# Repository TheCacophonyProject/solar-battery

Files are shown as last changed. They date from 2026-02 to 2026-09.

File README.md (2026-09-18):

# Solar battery

KiCad projects for the solar battery hardware. The board itself is in
[`solar-BQ25798`](solar-BQ25798), with the shared symbols and footprints pulled
in as the [`kicad-library`](kicad-library) submodule.

[`panel-solar-battery.py`](panel-solar-battery.py) panelises the board with
[KiKit](https://github.com/yaqwsx/KiKit) into `.generated-pcbs/`, and adds the
DRC exclusions for the footprints that the panelisation cuts through, so the
generated panel passes DRC.

### Install dependencies
KiCad supplies the `pcbnew` python module as a system package, and it can't be
installed with pip, so the virtual environment has to be able to see it:
- `sudo apt-get install kicad`
- `python3 -m venv --system-site-packages venv`
- `source venv/bin/activate`
- `pip install kikit`

Check both halves are importable before running anything:
- `python -c "import pcbnew, kikit"`

### Generating the panel
With the virtual environment activated, from the root of the repo:
- `python panel-solar-battery.py`

The script needs `kikit` on the `PATH` (it shells out to `kikit panelize`) as
well as `pcbnew` importable, which is why it is run from inside the virtual
environment rather than with the system python.

### Notes
- `.generated-pcbs/` is ignored by git — it is rebuilt from scratch on every
  run, and KiKit gives the footprints new UUIDs each time, so the DRC
  exclusions are only valid for the panel they were generated with.
- Getting the submodule if the checkout is fresh: `git submodule update --init`

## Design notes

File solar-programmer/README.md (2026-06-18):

# Solar Programmer

This is a hat to go on a Raspberry Pi Zero to help programming the solar batteries.

For the software to run look at [battery-programmer](https://github.com/TheCacophonyProject/battery-programmer)

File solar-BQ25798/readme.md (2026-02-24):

# Solar BQ25798

This is a 3S5P 18650 MPPT solar charger that uses a BQ25798 for the MPPT charger, BQ76920 for the balancer, and an ATtiny1616 for the charge controller.

The [firmware](https://github.com/TheCacophonyProject/solar-battery-firmware) and the PCB is a WIP.

## TODO

- Reduce trace resistances for power paths.
- Check resistance of the protection for the 18650, if too high look for alternatives.
- Tidy up of traces (bit of a mess at the moment)
- Add something so the ATtiny can check what version of the board it is (will maybe not be able to have the latest firmware work on all versions of the PCB)
- Bed of nails test fixture.
- Calculate shunt resistor value for the BQ76920 so it high enough for triggering over current discharges and short circuits.
- New 3D print for new layout of the components.

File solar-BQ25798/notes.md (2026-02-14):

## Notes from BQ25798 datasheet
### 1 Features
- Buck boost
- 1-4 cell batteries
- Input and charging current sensing
- Samples open circuit voltage MPPT
- Up to 24V, 30V absolute
- uA for battery only operation
- 500nA in charger shutdown mode
- Thermal regulation and thermal shutdown
- Input/battery OVP and OCP
- Charging safety timer
- Says only li-ion/li-polyer but the target charge voltage can be changed to suite a LiFePO4 4S setup 

### 7 Pin configuration and functions
- STAT: LED attached to help debugging while in development but is no needed in end product
- VBUS: recommended capacitor setup caused noise at low power charging. Check if adding more capacitance is not recommended.
- ~{QON}: Check if we need to use this for ship mode.
- ILIM_HIZ: Just pull up as the maximum current will be programmed through I2C
- SDRV: ship mosfet drive pin

### 8 Specifications
- Absolute max voltage of 30V
- Recommended max voltage of 24V
- 8.5 describes quiescent currents. Should use this to see what mode we should try to be in during night to reduce unneeded power losses.

### 9 Detailed Description
9.3.2 PROG Pin: Using 750MHz as that can work better at lower charge currents, and 3s cell count, even when using 4s LiFePO4 as the charge voltage range is 10-13.99V for 3s
- On boot should read the CELL bits to check that it is in the 3s and 750MHz

9.3.3 Device power up from battery without input source: This should only happen once when putting together the battery

9.3.4 Device Power Up from input Source: Need to check that in the process of putting the battery pack together it will boot up in combination with the cell balancer chip

9.3.4.1: Power Up REGN LDO: Don't use it for external circuits and not for ~{INT}

9.3.4.2 Poor Source qualification:
- Needs to stay in the voltage range while pulling up to 10mA
- PG_STAT is set high with a good source, ~{INT} is pulsed to notify host.
- If the voltage drops below the minimum voltage when pulling 10mA it will go into high impedance mode (EN_HIZ) for 7 minutes, we can trigger it to try again from the I2C master. We will want to do this as if a solar panel goes into shade for a bit we want it to try again.

9.3.4.3 ILIM_HIZ Pin:
- Will limit through software so this just gets pulled up to VREGN

9.3.4.4 Default VINDPM Setting:
- TODO

9.3.4.5 Input Source Type Detection:
- Runs Input Source Type Detection if AUTO_INDET_EN bit is set (default enabled)
- Do we want to just disable this?

9.3.4.5.1 D+/D– Detection Sets Input Current Limit:
- 

9.3.9.5:
- Set reg in  REG18_NTC_Control_1 for what voltage percentage it will be

9.3.10 ADC:
- Disable for low power when not needed.
- IBUS (positive in forward converter mode)
• IBAT (positive for charging)
• VBUS
• VPMID
• VBAT
• VSYS
• TS
• TDIE

9.3.11.1 STAT Pin:
- Can attached LED but remove LED for final product.

9.3.11.2 Interrupt to Host ( INT):
- Check status change when this triggers
- Disable some of the triggers for INT that we don't want.
- Just sends out a pulse, not held low

9.3.12 Ship FET Control:
TODO

9.3.12.1 Shutdown Mode:
- Will disable the I2C so probably not something we want to use.

9.3.12.2 Ship Mode
- Might be useful when trying to reduce power losses.

9.3.13 Protections:
- Monitor if any of the voltage and current monitoring triggers go off
- Monitor thermal regulation and set max temps

9.3.14 Serial interface:
- Just standard I2C device reading and writing to registers without crc

9.4.1:
- Handle the I2C WDT
- If I2C WDT triggers, make sure that we set all the registers again to what we want.

9.4.2 Register Bit Reset:
- register and the timer could be reset
to the default value by writing the REG_RST bit to 1
- Will want to use this on first power up from ATtiny so we know what state the chip is in

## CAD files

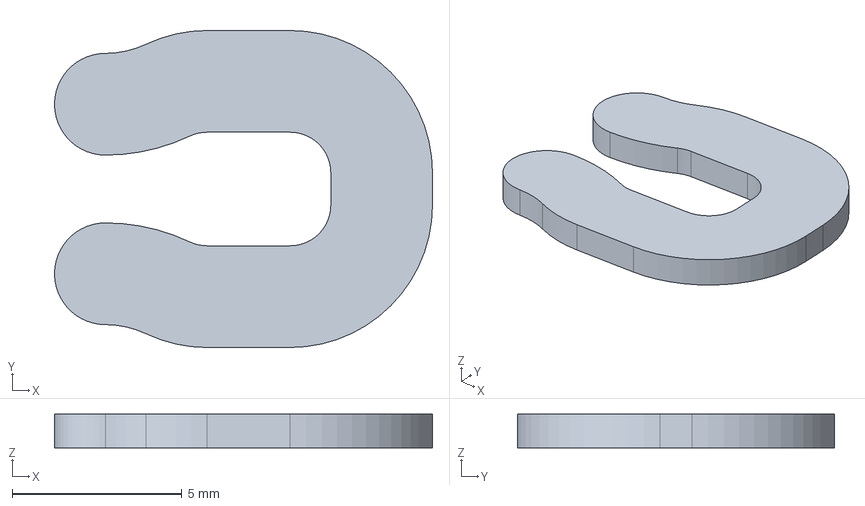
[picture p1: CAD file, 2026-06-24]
drawings/temp-sensor-thermal-relief.FCStd
11.2 x 9.35 x 1.00 mm

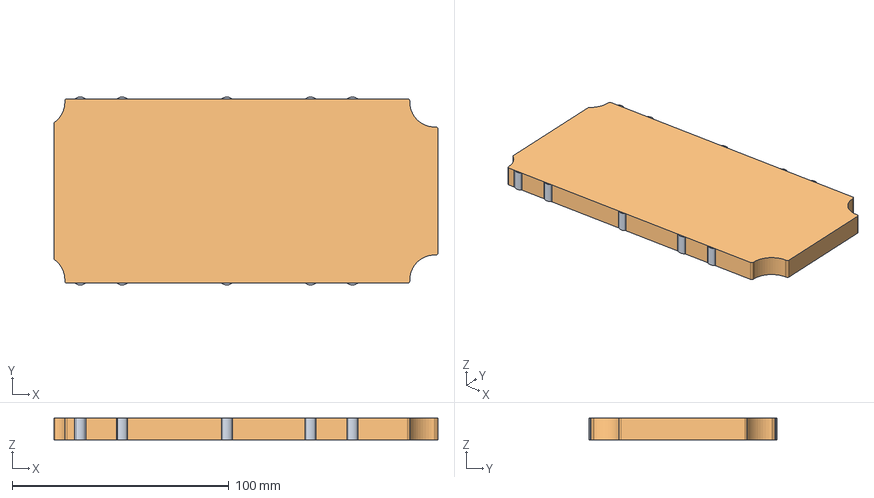
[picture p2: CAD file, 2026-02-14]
solar-BQ25798/drawings/solar-battery-boarder.FCStd
177.0 x 86.7 x 10.0 mm

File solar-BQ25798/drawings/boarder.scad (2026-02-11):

$fs=0.4;
$fa=4;


// ========== Boarder =============
// To make the boarder, we generate the boarder with the recommended maximum 
// measurements and then do an intersection from that with a rectangle.
// This makes it easy to resize/offset the boarder to fit in the case without 
// Needing to worry with being too big

// These are the maximum sizes that we want the boarder to be
width_max = 189;    // This is the width available for the back panel
depth_max = 89;     // This is the depth available for the back panel
corner_cutout = 15;             // For the corner cutouts this is the length that it is straight before it has its radius
corner_cutout_radius = 11.5;    // For the corner cutouts, this is the radius (not including the straight part)

// This is the size of the rectangle that will do an intersection with the maximum 
// boarder to get the final boarder.
// An offset is also used to make one end have more space for plugs.
depth = 85;
width = 177;
boarder_offset = 4;

// Distance from one battery cell to another.
bat_to_bat = 19.3;

h = 2;

module boarder2(height) {
    linear_extrude(height = height)
    import("/home/cam/Downloads/boarder3-Shape2DViewaaaaa.dxf"); 
}

module rec_from_points(x1, y1, x2, y2, r=0) {
    if (r == 0) {
        polygon(points=[[x1, y1], [x1, y2], [x2, y2], [x2, y1]]);
    } else {
        minkowski() {
            polygon(points=[[x1+r, y1+r], [x1+r, y2-r], [x2-r, y2-r], [x2-r, y1+r]]);
            circle(r = r);
        }
    }
}

tab_h=18;
tab_y=1.2;
tab_x=15.3;
tab_feet_y=4;
tab_feet_x=4.4;
tab_p = 35;

module tab_main() {
    // Body
    hull() {
        // Wider at the bottom to make putting it on the PCB easier.
        translate([0, 0, -1])
        linear_extrude(height = 1) 
        rec_from_points(x1 = -tab_x/2, y1 = -tab_y, x2 = tab_x/2, y2 = tab_y, r=0.4);
        linear_extrude(height = tab_h) 
        rec_from_points(x1 = -tab_x/2, y1 = -tab_y/2, x2 = tab_x/2, y2 = tab_y/2, r=0.4);
    }
    hull() {
        // Wider at the bottom to make putting it on the PCB easier.
        translate([0, -tab_y, h8])
        linear_extrude(height = 1) 
        rec_from_points(x1 = -tab_x/2, y1 = -tab_y/2-2, x2 = tab_x/2, y2 = tab_y, r=0.4);
        
        translate([0, 0, tab_h-1])
        linear_extrude(height = 1) 
        rec_from_points(x1 = -tab_x/2, y1 = -tab_y/2-1, x2 = tab_x/2, y2 = tab_y/2, r=0.4);
    }

    difference() {
        hull() {
            extra_width=5;
            translate([-(0)/2, tab_feet_y/2, -1])
            linear_extrude(height=2)
            rec_from_points(x1 = -bat_to_bat/2-extra_width/2, y1 = -tab_feet_y/2-1, x2 = bat_to_bat/2+extra_width/2, y2 = tab_feet_y/2);

            translate([-(0)/2, tab_feet_y/2-1.4, 5])
            cube([bat_to_bat+extra_width, 0.01, 1], center=true);
        }

        translate([0, -tab_p+39.85, -2])
        cylinder(d=3.3+1.8, h=5); 

        translate([bat_to_bat/2, -tab_p+39.85, -2])
        cylinder(d=3.3+1.8, h=5);
        translate([-bat_to_bat/2, -tab_p+39.85, -2])
        cylinder(d=3.3+1.8, h=5);    
    }   
}
// !tab_main();

module tab_positive() {
    tab_main();
    hull() {
        translate([0, 0, tab_h/2])
        cube([tab_x/3*2, tab_y, tab_h], center=true);
        translate([0, -2.3/2, tab_h/2])
        cube([tab_x/3, 2.3, tab_h], center=true);
    }
}

module tab_negative() {
    rotate([0, 0, 180]) {
        tab_main();

        translate([0, -13/2, -1])
        linear_extrude(height = tab_h)
        rec_from_points(-4, -6.5, 4, 7, r=1);

        translate([5.5, -2.7, -1])
        rotate([0, 1.9, 90])
        rotate_extrude(angle=90)
        translate([1.5, 0, 0])
        square([1, tab_h]);

        translate([-5.5, -2.7, -1])
        rotate([-1.9, 0, 0])
        rotate_extrude(angle=90)
        translate([1.5, 0, 0])
        square([1, tab_h]); 
    }
}
//!tab_negative();

module electronics_cutout() {
    translate([0, 0, -1])
    linear_extrude(height = 2)
    rec_from_points(x1 = -bat_to_bat+5, y1 = -33, x2 = -5, y2 = 33, r=1);
    
    hull() {
        translate([0, 0, 1-0.1])
        linear_extrude(height = 0.1)
        rec_from_points(x1 = -bat_to_bat+5, y1 = -33, x2 = -5, y2 = 33);

        translate([-bat_to_bat/2, 0, 6])
        linear_extrude(height = 0.01)
        rec_from_points(x1 = 0.01, y1 = -33, x2 = -0.01, y2 = 33);
    }
}
//!electronics_cutout();

screw_head_diameter = 6.2;
screw_hole_y = 39.85;
screw_hole_dx = bat_to_bat/2;

screw_diameter_clearance = 3.5;
screw_diameter_pilot = 2.6;

module screw_head_cutout() {
    a = 6;
    translate([0, 0, -1])
    cylinder(d=screw_diameter_clearance, h=h8);
    
    translate([0, 0, a-1.5])
    cylinder(d1=screw_diameter_clearance, d2=screw_head_diameter, h=1.5);
    hull() {    
        translate([0, 0, a])
        cylinder(d=screw_head_diameter, h=h8);
        
        translate([0, 10, h8/2+a+5])
        cube([screw_head_diameter*2, 1, h8], center=true);
    }
}
//!screw_head_cutout();

module screw_head_cutout_flat() {
    a = 5;
    translate([0, 0, -1])
    cylinder(d=screw_diameter_clearance, h=h8+1);
    
    hull() {    
        translate([0, 0, a])
        cylinder(d=screw_head_diameter, h=h8);
        
        translate([0, 10, h8/2+a])
        cube([screw_head_diameter*2, 1, h8], center=true);
    }
}
//!screw_head_cutout_flat();

// A 
module support_bar(width, length) {
    r = 4;
    wall_t = 1.3;

    dx = cos(30)*r*2+wall_t;
    dy = sin(60)*dx;

    
    union() {
        difference() {
            cube([length, width, 30], center=true);
            translate([-length/2-0.5*dx, -dy*1.5, 0])
            for (n = [0:4]) {
                translate([0, dy*2*n, 0])
                for (i = [0:30]) {
                    translate([dx*i, 0, 0])
                    rotate([0, 0, 30])
                    cylinder(r=r, $fa=60, h=31, center=true);
                    translate([0.5*dx+i*dx, dy, 0])
                    rotate([0, 0, 30])
                    cylinder(r=r, $fa=60, h=31, center=true);
                }
            } 
        }

        difference() {
            cube([length, width, 30], center=true);
            cube([length+1, width-wall_t*2, 40], center=true);
        }
    }
}
//!support_bar(20, 100);

bat_d = 18.8;
bat_h=1;
tab_n = -35;
module battery() {
    render(convexity=2)
    union() {
    bat_c=0;
    tab_h=17;
    tab_t=2;
    tab_x=14.2;
    tab_feet_y=2.8;
    tab_feet_x=4;

    // Main 18650 cell cell
    translate([0, tab_n+bat_c, bat_d/2+bat_h])
    rotate([-90, 0, 0])
    minkowski() {
        sphere(r=bat_c);
        cylinder(d=bat_d-bat_c*2,h=tab_p-tab_n-bat_c*2);
    }

    // Battery silkscreen cutout
    translate([0, 0, -1])
    linear_extrude(height=10)
    rec_from_points(x1=-3, y2=16.6, x2=3, y1=-8, r=0.5);

    translate([0, tab_n, 0])
    tab_negative();
    translate([0, tab_p, 0])
    tab_positive();
    }
}
// !battery();

// Test cells
module test_cells()
scale([1, -1, 1])
union() {
    count = 2;
    difference() {
        translate([bat_to_bat/2*count-bat_to_bat/2, 0, h8/2])
        cube([bat_to_bat*count, depth, h8], center=true);

        // Batteries
        for (i = [0:count-1]) {
            //battery();
            translate([i*bat_to_bat, 0, 0])
            //rotate([0, 0, (i+1)*180])
            battery();
        }

        // Cell protection cutout
        for (i = [0:count]) {
            translate([i*bat_to_bat, 0, 0])
            electronics_cutout();
            
            scale([1, -1, 1])
            translate([i*bat_to_bat, 0, 0])
            electronics_cutout();
        }

        mid_joints = [false, false, true, false, true];
        for (i = [0:count*2-2]) {
            translate([screw_hole_dx*i, screw_hole_y, 0])
            cylinder(d=screw_diameter_pilot, h=40, center=true);

            if (mid_joints[i]) {
                translate([screw_hole_dx*i, screw_hole_y, 0])
                screw_head_cutout();
            }
        }

        mid_joints2 = [true, false, false, false, false];
        scale([1, -1, 1])
        for (i = [0:count*2-2]) {
            translate([screw_hole_dx*i, screw_hole_y, 0])
            cylinder(d=screw_diameter_pilot, h=40, center=true);

            if (mid_joints2[i]) {
                translate([screw_hole_dx*i, screw_hole_y, 0])
                screw_head_cutout();
            }
        }
    }

    translate([bat_to_bat/2*count-bat_to_bat/2, 0, 0.2])
    difference() {
        cube([bat_to_bat*count, depth, 0.4], center=true);
        cube([bat_to_bat*count-1.6, depth-1.6, 0.6], center=true);
    }
}
// test_cells();

battery_top_rotations = [0, 0, 1, 1, 1, 0, 0];
battery_bottom_rotations = [1, 1, 1, 0, 0, 1, 1, 1];
temp_sensors = [1, 0, 0, 1, 0, 0, 0];

h8 = 19/2+1;

// Top side, inside bit.
// Flipping it around as the y axis is reversed in kicad to openscad
module top_side_inner()
scale([1, -1, 1])
difference() {
    // Main body
    translate([0, 0, 0.01])
    
    boarder2(h8);
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

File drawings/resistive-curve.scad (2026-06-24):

// This file is used to generate a DXF that will be the tack for the resistance
// The resistance we can calculate from:
// - Track width (chosen from KiCAD import option), 
// - Total length (will echo estimated total length) 
// - copper thickness (normally 17.5um on internal copper layers)

h = 40; //
l = 142;
x1 = 8;
t1 = 0.7;

c = 0.0172;

$fs=0.2;

estimate_total_length = l/t1*(h-t1*2);

echo(Length=estimate_total_length);

rho = 1.68e-8; // Ω·m
length_m = estimate_total_length/1000;
height_m = 0.0175/1000;
width_m = t1/1000/2;
resistance = 1.68e-8*length_m/(width_m * height_m);
echo(Resistance=resistance);

module slice2() {
    a = h/2-t1*1.5;
    translate([0, a/2])
    cube([t1, a, 1], center=true);

    translate([-t1*1, h/2-t1*1.5])
    intersection() {
        difference() {
            cylinder(d=t1*3, h=1, center=true);
            cylinder(d=t1, h=2, center=true);
        }
        translate([0, 0, -1])
        cube([t1*4, t1*4, 2]);
    }

}


function pos_bump(x) = (-10 < x && x < 3) ? -12 : 0;
function neg_bump(x) = (48 < x && x < 62) ? -12 : 0;


// projection()
union() {
    for (i = [0:l/t1/2]) {
        x = -l/2-x1+i*t1*2;
        translate([x, pos_bump(x), 0])
        if (i%2==0) {
            translate([0, 0, 0])
            slice2();    
            translate([-t1*2, 0, 0])
            mirror([1, 0, 0])
            slice2();
        }
    }

    mirror([0, 1, 0])
    for (i = [0:l/t1/2]) {
        x = -l/2-x1+i*t1*2+t1*2;
        translate([x, neg_bump(x), 0])
        if (i%2==0) {
            translate([0, 0, 0])
            slice2();    
            translate([-t1*2, 0, 0])
            mirror([1, 0, 0])
            slice2();
        }
    }

    translate([-l/2-x1-t1*2, 0, 0])
    hull() {
        cylinder(d=t1, h=1, center=true);
        
        translate([0, -h/2+t1/2, 0])
        cylinder(d=t1, h=1, center=true);
    }


    i = l/t1/2;
    a = i - i%1;
    x = -l/2-x1+a*t1*2;
    translate([x, 0, 0])
    hull() {
        cube([t1, 1, 1], center=true);
        
        translate([0, h/2-t1-5, 0])
        cube([t1, 1, 1], center=true);
    }
}

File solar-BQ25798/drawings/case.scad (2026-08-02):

$fs=0.4;
$fa=4;

// $fa = 8;
// $fs = 0.8;

output = "bottom_side_inner";

// ========== Boarder =============
// To make the boarder, we generate the boarder with the recommended maximum 
// measurements and then do an intersection from that with a rectangle.
// This makes it easy to resize/offset the boarder to fit in the case without 
// Needing to worry with being too big

// These are the maximum sizes that we want the boarder to be
width_max = 189;    // This is the width available for the back panel
depth_max = 89;     // This is the depth available for the back panel
corner_cutout = 15;             // For the corner cutouts this is the length that it is straight before it has its radius
corner_cutout_radius = 11.5;    // For the corner cutouts, this is the radius (not including the straight part)

// This is the size of the rectangle that will do an intersection with the maximum 
// boarder to get the final boarder.
// An offset is also used to make one end have more space for plugs.
depth = 85;
width = 177;
boarder_offset = 4;

// Distance from one battery cell to another.
bat_to_bat = 19.3;

h = 2;

screw_head_diameter = 6.2;
screw_hole_y = 39.85;
screw_hole_dx = bat_to_bat/2;
screw_diameter_clearance = 3.5;
screw_diameter_pilot = 2.6;

plug_screw_x = 87.5;

solid_infill_diameter = 10;

bat_d = 18.8;
bat_h=1;
tab_n = -35;

battery_top_rotations = [0, 0, 1, 1, 1, 0, 0];
battery_bottom_rotations = [1, 1, 1, 0, 0, 1, 1, 1];
temp_sensors = [1, 0, 0, 1, 0, 0, 0];

h8 = 19/2+1;

tab_h=18;       // Height of the battery tab hole
tab_y=1.2;      // Thickness of the battery tab hole
tab_x=15.3;     // x position of the battery tab
tab_feet_y=4;
tab_feet_x=4.4;
tab_p = 35;

// Buzzer
buzzer_pos_x = 71.4;
buzzer_pos_y = -30.1;
buzzer_d = 10;

// DXF paths
programmer_dxf = "solar-BQ25798-programmer-border.dxf";
connectors_dxf = "solar-BQ25798-connectors-border.dxf";
components_dxf = "solar-BQ25798-B_components-border.dxf";


// Thermal switch
thermal_switch_pos_x = 71;
thermal_switch_pos_y = 23;
thermal_switch_pos_z = 6.45;
thermal_switch_size_x = 8.9;
thermal_switch_size_y = 28;
thermal_switch_size_z = 5.1;
thermal_switch_wall_t = 1.2;

// boarder is a function to make the boarder with given height using a dxf file.
module boarder(height) {
    linear_extrude(height = height)
    import("solar-battery-boarder-case.dxf"); 
}

module import_kicad_dxf(name, h) {
    // scale(25.4)
    linear_extrude(height = h)
    import(name); 
}

// Helper module to make a rectangle from 2 x and 2 y points with options rounded corners.
module rec_from_points(x1, y1, x2, y2, r=0) {
    if (r == 0) {
        polygon(points=[[x1, y1], [x1, y2], [x2, y2], [x2, y1]]);
    } else {
        minkowski() {
            polygon(points=[[x1+r, y1+r], [x1+r, y2-r], [x2-r, y2-r], [x2-r, y1+r]]);
            circle(r = r);
        }
    }
}

module rec_from_pos_size(pos_x, pos_y, len_x, len_y, r=0) {
    x1 = pos_x-len_x/2;
    x2 = pos_x+len_x/2;
    y1 = pos_y-len_y/2;
    y2 = pos_y+len_y/2;
    rec_from_points(x1 = x1, y1 = y1, x2 = x2, y2 = y2, r=r);
}

// Main part of the battery tab, used as part to make the positive and negative tab.
module tab_main() {
    // Body
    hull() {
        // Wider at the bottom to make putting it on the PCB easier.
        translate([0, 0, -1])
        linear_extrude(height = 1) 
        rec_from_points(x1 = -tab_x/2, y1 = -tab_y, x2 = tab_x/2, y2 = tab_y, r=0.4);
        translate([0, -0.5, 0])
        linear_extrude(height = tab_h/2) 
        rec_from_points(x1 = -tab_x/2, y1 = -tab_y/2, x2 = tab_x/2, y2 = tab_y/2, r=0.4);
    }
    translate([0, -0.5, tab_h/2])
    linear_extrude(height = tab_h/2) 
    rec_from_points(x1 = -tab_x/2, y1 = -tab_y/2, x2 = tab_x/2, y2 = tab_y/2, r=0.4);

    hull() {
        // Wider at the bottom to make putting it on the PCB easier.
        translate([0, -tab_y, h8])
        linear_extrude(height = 1) 
        rec_from_points(x1 = -tab_x/2, y1 = -tab_y/2-2, x2 = tab_x/2, y2 = tab_y, r=0.4);
        
        translate([0, 0, tab_h-1])
        linear_extrude(height = 1) 
        rec_from_points(x1 = -tab_x/2, y1 = -tab_y/2-1, x2 = tab_x/2, y2 = tab_y/2, r=0.4);
    }

    difference() {
        hull() {
            extra_width=5;
            translate([-(0)/2, tab_feet_y/2, -1])
            linear_extrude(height=2)
            rec_from_points(x1 = -bat_to_bat/2-extra_width/2, y1 = -tab_feet_y/2-1, x2 = bat_to_bat/2+extra_width/2, y2 = tab_feet_y/2);

            translate([-(0)/2, tab_feet_y/2-1.4, 5])
            cube([bat_to_bat+extra_width, 0.01, 1], center=true);
        }

        translate([0, -tab_p+39.85, -2])
        cylinder(d=6, h=6); 

        translate([bat_to_bat/2, -tab_p+39.85, -2])
        cylinder(d=6, h=6);
        translate([-bat_to_bat/2, -tab_p+39.85, -2])
        cylinder(d=6, h=6);    
    }   
}
// !tab_main();

// tab_positive, cutout for the tab on the positive side 
module tab_positive() {
    tab_main();
    hull() {
        translate([0, -1, tab_h/2])
        cube([tab_x/3*2, 0.1, tab_h], center=true);
        translate([0, -2.3/2, tab_h/2])
        cube([tab_x/3, 2.3, tab_h], center=true);
    }
}
// !tab_positive();

// tab_negative, cutout for the tab on the negative side
module tab_negative() {
    rotate([0, 0, 180]) {
        tab_main();

        translate([0, -13/2, -1])
        linear_extrude(height = tab_h)
        rec_from_points(-4, -6.5, 4, 6, r=1);

        translate([5.5, -2.8, -1])
        rotate([0, 1.9, 90])
        rotate_extrude(angle=90)
        translate([1.5, 0, 0])
        square([1, tab_h]);

        translate([-5.5, -2.8, -1])
        rotate([-1.9, 0, 0])
        rotate_extrude(angle=90)
        translate([1.5, 0, 0])
        square([1, tab_h]); 
    }
}
// !tab_negative();

// cell_protection_cutout, cutout between the cells where the cell protection SMD components are
module cell_protection_cutout() {
    translate([0, 0, -1])
    linear_extrude(height = 2)
    rec_from_points(x1 = -bat_to_bat+5, y1 = -33, x2 = -5, y2 = 33, r=1);
    
    hull() {
        translate([0, 0, 1-0.1])
        linear_extrude(height = 0.1)
        rec_from_points(x1 = -bat_to_bat+5, y1 = -33, x2 = -5, y2 = 33);

        translate([-bat_to_bat/2, 0, 6])
        linear_extrude(height = 0.01)
        rec_from_points(x1 = 0.01, y1 = -33, x2 = -0.01, y2 = 33);
    }
}
// !cell_protection_cutout();

// screw_head_cutout, cutout for the screw head, has a few angle to make printing upside down doable without supports.
module screw_head_cutout() {
    a = 6;
    translate([0, 0, -1])
    cylinder(d=screw_diameter_clearance, h=h8);
    
    translate([0, 0, a-2])
    cylinder(d1=screw_diameter_clearance, d2=screw_head_diameter, h=2);


    hull() {    
        translate([0, 5, a-0.5])
        cylinder(d=1, h=a);

        translate([0, 0, a-1.5])
        cylinder(d=screw_diameter_clearance, h=a);

        translate([0, 0, a])
        cylinder(d=screw_head_diameter, h=h8);
        
        translate([0, 10, h8/2+a+5])
        cube([screw_head_diameter*2, 1, h8], center=true);
    }
}
// !rotate([0, 0, 90]) screw_head_cutout();

// screw_head_cutout_flat, cutout for the screw head. Not intended to be printed upside down.
module screw_head_cutout_flat() {
    a = 5;
    translate([0, 0, -1])
    cylinder(d=screw_diameter_clearance, h=h8+1);
    
    hull() {    
        translate([0, 0, a])
        cylinder(d=screw_head_diameter, h=h8);
        
        translate([0, 10, h8/2+a])
        cube([screw_head_diameter*2, 1, h8], center=true);
    }
}
// !screw_head_cutout_flat();

// battery, cutout for the battery. Includes the positive, negative tabs and the silkscreen cutout.
module battery() {
    render(convexity=2)
    union() {
    bat_c=0;
    tab_h=17;
    tab_t=2;
    tab_x=14.2;
    tab_feet_y=2.8;
    tab_feet_x=4;

    // Main 18650 cell cell
    translate([0, tab_n+bat_c, bat_d/2+bat_h])
    rotate([-90, 0, 0])
    minkowski() {
        sphere(r=bat_c);
        cylinder(d=bat_d-bat_c*2,h=tab_p-tab_n-bat_c*2);
    }

    // Battery silkscreen cutout
    translate([0, 0, -1])
    linear_extrude(height=10)
    rec_from_points(x1=-4, y2=20, x2=4, y1=-10, r=0.5);

    translate([0, tab_n, 0])
    tab_negative();
    translate([0, tab_p, 0])
    tab_positive();
    }

    // Top hole
    translate([0, 0, 10])
    linear_extrude(height = 20) 
    rec_from_points(x1 = -5, y1 = -20, x2 = 5, y2 = 20, r=1.5);
}
// !battery();

// test_cell. A smaller print to test the fitting of the battery cells.
module test_cells() {
    scale([1, -1, 1]) union() {
        count = 2;
        difference() {
            translate([bat_to_bat/2*count-bat_to_bat/2, 0, h8/2])
            cube([bat_to_bat*count, depth, h8], center=true);

            // Batteries
            for (i = [0:count-1]) {
                //battery();
                translate([i*bat_to_bat, 0, 0])
                //rotate([0, 0, (i+1)*180])
                battery();
            }
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

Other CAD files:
drawings/Case-hole-cutouts.FCStd

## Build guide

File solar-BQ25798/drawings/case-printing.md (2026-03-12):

# Printing Instructions

## Parts

These parts can be generated by installing openscad and running `render_case.sh` or will be available as part of the github release.

- bottom_side_inner.stl
- bottom_side_outer.stl
- top_side_inner.stl
- top_side_outer.stl
- plug_cover.stl

## Slicer settings

Using Prusa Slicer these are some of the setting that I use.

- Fill density: 10%
- Layer height: 0.3mm
- Perimeters: 2
- Horizontal Shell, solid layers: Top 4
- Horizontal Shell, solid layers: Bottom 2

## Solid Infill Modifier Setup

Each .stl file has a matching .stl modifier file for setting part of the print to 100% infill. This is for better strength around the screws.

To set this up on Prusa Slicer follow these steps, we will use `bottom_side_inner.stl` for the example:

- Import `bottom_side_inner.stl`
- Right click on the part in the 3D viewer -> `Add modifier` -> `Load ...`
- Select `bottom_side_inner_solid_infill.stl`
- You should see multiple cylinders where the screw holes are.
- In the menu on the right side right click on `bottom_side_inner_solid_infill` -> `Infill`
- At the bottom you can now set the modifier infill to 100%

Now when you slice the file you should see that around the screw holes the infill is 100%

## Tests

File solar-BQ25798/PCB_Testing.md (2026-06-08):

# PCB Testing

This lays out the different things we want to be able to test (and how to) for each PCB.

## Manual testing

Before we have a testing PCB rig setup with a automated testing procedure we need to test the PCBs manually.

## Pack level testing

- Pack over voltage protection: Put in 4.1V cells and make sure it is not charging the pack to more than 12.3V total.
- Cell under voltage protection: Put in 3.3V cells and make sure under voltage protection kicks in if a high load (enough to drop the cell voltage to below 3V) will trigger the under voltage protection.
- Pack Over Current Protection: Will all 15 cells in make sure it can draw 2.5A, should cut off at around 3A
- Pack short Circuit Protection: Short the output with the 15 cells to make sure the short circuit protection triggers.
- Sanity check on temperature sensor (check that the temperature is around the correct value) Maybe this can be done in software, checking that all internal temperature sensors read about the same on the initial startup?

- Over temperature protection: One at a time, apply heat to the temperature sensor to make sure the

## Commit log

2025-06-30 Update layout
    [LTC4015.kicad_sch, cell_1.kicad_sch, kicadpartsplacer.kicad_pcb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]
2025-06-30 files tidy up
    [kicadpartsplacer.kicad_pcb]
2025-11-12 BQ25798 WIP
    [BQ25798.kicad_sch, LTC4015.kicad_sch, attiny1616.kicad_sch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]
2025-11-19 Update 3D CAD files
    [boarder.scad]
2025-12-11 Solar battery WIP
    [BQ25798.kicad_sch, BQ76920.kicad_sch, attiny1616.kicad_sch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]
2025-12-11 Version v0.0.2
    [BQ25798.kicad_sch, attiny1616.kicad_sch, solar-BQ25798.kicad_pcb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]
2026-01-14 Update printed cell holders
    [boarder.scad]
2026-02-11 Use dxf from FreeCAD modle
    [boarder.scad]
2026-02-14 Tidy up of files
    [attiny1616.kicad_sch, battery_tab_plated_slot.FCStd, case.scad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]
2026-02-18 Update battery PCB
    [BQ25798.kicad_sch, BQ76920.kicad_sch, attiny1616.kicad_sch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]
2026-02-19 Update shunt resistor
    [BQ76920.kicad_sch, solar-BQ25798.kicad_pcb]
2026-02-24 Update case and minor PCB changes
    [case.scad, solar-BQ25798.kicad_pcb]
2026-03-12 Update case printing
    [case.scad]
2026-03-18 Fix buzzer
    [attiny1616.kicad_sch, solar-BQ25798.kicad_pcb]
2026-03-18 Cell protection WIP
    [cell-protection.kicad_pcb, cell-protection.kicad_sch, cell.kicad_sch]
2026-03-19 Update 22mΩ component
    [cell.kicad_sch, solar-BQ25798.kicad_pcb]
2026-04-21 Add solar programmer
    [solar-programmer.kicad_pcb, solar-programmer.kicad_sch]
2026-06-08 Update to KiCAD 10
    [BQ25798.kicad_sch, BQ76920.kicad_sch, attiny1616.kicad_sch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]
2026-06-14 Fix pin for serial out and other small fixes
    [BQ76920.kicad_sch, attiny1616.kicad_sch, cell.kicad_sch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]
2026-06-14 Update some components attribute to exclude from position file
    [BQ25798.kicad_sch, attiny1616.kicad_sch, solar-BQ25798.kicad_pcb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]
2026-06-15 Improve optional shunt resistor
    [attiny1616.kicad_sch, solar-BQ25798.kicad_pcb, solar-BQ25798.kicad_sch]
2026-06-15 Reduce number of different resistor and capacitor values
    [BQ25798.kicad_sch, BQ76920.kicad_sch, attiny1616.kicad_sch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]
2026-06-18 Update solar-programmer
    [solar-programmer.kicad_pcb, solar-programmer.kicad_sch]
2026-06-18 Update components LCSC parts
    [BQ25798.kicad_sch, solar-BQ25798.kicad_pcb, solar-BQ25798.kicad_sch]
2026-06-24 Add heating element
    [BQ25798.kicad_sch, attiny1616.kicad_sch, resistive-curve.scad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]
2026-06-26 Update buzzer and 3D files
    [attiny1616.kicad_sch, solar-BQ25798.kicad_sch]
2026-07-24 Update case
    [case.scad]
2026-08-02 Updated kicad library
2026-08-02 Getting ready for v0.3.0
    [BQ25798.kicad_sch, BQ76920.kicad_sch, attiny1616.kicad_sch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]
2026-08-24 Add pull up resistor for /CE and updated charger temperature range resistors
    [BQ25798.kicad_sch, solar-BQ25798.kicad_pcb]
2026-08-25 Move output filter
    [solar-BQ25798.kicad_pcb]
2026-09-10 Add panel generation
    [solar-BQ25798.kicad_pcb]
2026-09-10 Small tidy up
    [solar-BQ25798.kicad_pcb, solar-BQ25798.kicad_sch]
2026-09-11 Tidy up
    [BQ25798.kicad_sch, BQ76920.kicad_sch, attiny1616.kicad_sch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]
2026-09-11 Fix ERC errors
    [BQ25798.kicad_sch, BQ76920.kicad_sch, attiny1616.kicad_sch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]
2026-09-13 Fix panelize
    [solar-BQ25798.kicad_pcb]
2026-09-19 fix panel bom in kicad-release.yml
2026-09-22 Change p-mosfet and fuse LCSC part number
    [cell.kicad_sch, solar-BQ25798.kicad_pcb, solar-BQ25798.kicad_sch]
2026-09-23 Update some component parts for stock reasons
    [cell.kicad_sch, solar-BQ25798.kicad_pcb]
2026-09-23 Update LCSC part numbers
    [BQ76920.kicad_sch, cell.kicad_sch, solar-BQ25798.kicad_pcb]
